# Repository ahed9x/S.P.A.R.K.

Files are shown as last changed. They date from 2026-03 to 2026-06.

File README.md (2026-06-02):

---
title: "S.P.A.R.K."
author: "ahed9x"
description: "ping pong no camera refree"
created_at: "2026-01-07"
---

# ⚡ S.P.A.R.K.

> an acoustic ping pong referee. 15 sensors, 3 esp32s, zero cameras.

## why i built this
last summer i wasted weeks trying to train a computer vision model to track a ping pong ball. the frame rates were terrible, the processing lagged, and it basically sucked. then one day i was sitting by the table waiting for my turn, closed my eyes, and realized i could track the score and whose turn it was just by listening to the bounces. 

it clicked that acoustic time-of-flight on edge microcontrollers would be way faster for catching a 100km/h ball without needing a crazy gpu. so i scrapped the camera and built this instead.

## what it actually is
SPARK is a fully automated table-tennis referee. it uses 4 i2s microphones on the corners of the table to listen for the ball, and calculates the exact x/y coordinate of the hit using time-difference-of-arrival (TDOA) math. i also glued 10 lm393 piezo sensors under the table and net to catch instant physical vibrations. 

everything gets processed by a master esp32 that runs the game logic, drives a 5m led scoreboard, and yells the score out through a speaker.



## the architecture (why 3 chips?)
at first i tried to run this on one or two chips, but the interrupts kept crashing. ping pong is way too fast. if the esp is busy updating the led strip, it misses the sound of the bounce. 

the biggest hurdle was clock sync. all 4 microphones MUST share the exact same internal hardware clock. if i split them across different chips, the microsecond time-of-flight math drifts and the coordinates get completely ruined. 

so i split the load:
* **s3 alpha (left side):** handles all 4 mics (to keep the clock perfectly synced) + the left side piezos.
* **s3 beta (right side):** handles the right side piezos + the net piezos.
* **master wroom:** runs the actual game logic, the bme680, audio amp, and led scoreboard.

alpha and beta just act as raw sensor nodes and fire data back to the master over hardwired UART.

## the math & physics
**speed of sound drift:** the speed of sound literally changes depending on how hot the room is. if i don't account for this, the math drifts. i threw a bme680 sensor on the master board to constantly read the room temp in celsius and update the velocity variable in real time.

**tdoa (time difference of arrival):** 4 mics give us 3 independent arrival time differences. instead of running crazy non-linear solvers that would lag the esp, the system linearizes the equations into a 3x3 matrix and solves it instantly using cramer's rule. 

**analog vs digital piezos:** initially i tried reading the piezos via analog pins. terrible idea. the esp wasted too many cycles polling the voltage. i switched to lm393 modules so the hardware handles the threshold tuning. when a ball hits, it fires a digital HIGH, triggering a zero-latency hardware interrupt.

## the wiring nightmare
no custom pcb yet, it's all point-to-point. 

running raw uart and i2s data wires across a 2.7 meter table turns them into giant antennas that pick up massive emi static from the 15A power supply. it was a devastating process figuring out why the signals were garbage. i ended up using cat5e ethernet cables for the long data runs—twisting the rx/tx lines with ground wires inside the cat5e physically shields the signals.

Schematic_New-Projecterewrewrwer_2026-03-12 (1)
[Schematic_New-Projecterewrewrwer_2026-03-12 (1).pdf](https://github.com/user-attachments/files/28225490/Schematic_New-Projecterewrewrwer_2026-03-12.1.pdf)

## 3d printed parts & acoustic shadows
i couldn't drill holes in the table (obviously), so everything mounts with vhb tape. 

i also originally wanted to mount the mics deep underneath the table to protect them, but realized the thick wooden edge creates an "acoustic shadow" that bends and delays the sound wave. that delay completely destroys the millimeter accuracy. i had to design custom fusion 360 brackets that extend out and keep the mic entry hole perfectly flush with the table surface.

full assembly
ESP Case
Mic Holder

## the build / bom
the whole thing costs around 6492 EGP (like 125 USD). 




* 2x ESP32-S3-N16R8
* 1x ESP32 WROOM
* 4x INMP441 MEMS Mics
* 10x LM393 Piezo Modules
* 1x BME680 Sensor
* 1x MAX98357A I2S Amp + 3W Speaker
* 5m WS2812B LEDs + 15A PSU
* lots of CAT5E cable

all cad files are in the `/cad` folder on this repo. 

image (1)
image (2)

## quick start
1. flash all 3 esps using platformio.
2. grab the mac addresses of the alpha and beta chips and drop them into `shared/spark_protocol.h` on the master.
3. put your game audio `.wav` files (16-bit pcm, mono) onto a fat32 micro sd card and pop it into the master module.
4. connect to the `SPARK_Table` wifi network, hit `192.168.4.1`, and hit new game.

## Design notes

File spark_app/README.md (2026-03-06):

# spark_app

A new Flutter project.

## Getting Started

This project is a starting point for a Flutter application.

A few resources to get you started if this is your first Flutter project:

- [Lab: Write your first Flutter app](https://docs.flutter.dev/get-started/codelab)
- [Cookbook: Useful Flutter samples](https://docs.flutter.dev/cookbook)

For help getting started with Flutter development, view the
[online documentation](https://docs.flutter.dev/), which offers tutorials,
samples, guidance on mobile development, and a full API reference.

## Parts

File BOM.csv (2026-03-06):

Category | Qty | Item Name | Purpose / Notes | Estimated Price (EGP) | link
MCU & Logic | 2 | ESP32-S3-1N16R8 WiFi + Bluetooth | S3 Alpha & Beta (Audio Buffering & Interrupts) | 900 | https://store.fut-electronics.com/collections/all/products/esp32-s3-devkitc-1-copy?variant=43309674496109
MCU & Logic | 1 | ESP32-S3 (DevKitC-1) | Master WROOM (Game Engine & API Server) | 380 | https://store.fut-electronics.com/collections/all/products/esp32-s3-devkitc-1?variant=42265460179053
MCU & Logic | 1 | 4 Channels I2C Logic Level Converter | 3.3V to 5V shifter for the LED strip data line | 45 | https://store.fut-electronics.com/collections/all/products/logic-level-converter-1?variant=40470370025581
MCU & Logic | 1 | Micro SD Card Module (5V Compatible) | Reads audio files and local player JSON data | 60 | https://www.ram-e-shop.com/ar/shop/kit-sd-card-module-micro-sd-card-module-for-arduino-or-mcu-7056
MCU & Logic | 1 | Micro SD Card 32 GB HC10 | High-speed storage for web assets and audio | 375 | https://www.ram-e-shop.com/ar/shop/micro-sd-32gb-micro-sd-card-32gb-hc10-krt-dhkr-mymwry-micro-sd-s-32-jyjbyt-6298
Sensors & Audio | 4 | INMP441 MEMS Microphone - I2S | Corner acoustic ToF mapping | 1120 | https://store.fut-electronics.com/collections/all/products/inmp441-mems-microphone-i2s?variant=43298631417965
Sensors & Audio | 10 | Piezo Sensor Element 35mm | Vibration sensing and acoustic ping emission | 350 | https://store.fut-electronics.com/collections/all/products/piezo-sensor-element-35mm?variant=40109101547629
Sensors & Audio | 10 | Vibration Switch Module SW1801P | Using the LM393 chips for digital hardware interrupts | 250 | https://makerselectronics.com/product/vibration-switch-module-sw1801p/
Sensors & Audio | 1 | BME680 Environmental Sensor | Speed of Sound calculation & enclosure thermal monitoring | 490 | https://store.fut-electronics.com/collections/all/products/bme680-environmental-sensor-pressure-temperature-humidity-voc-gas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
Sensors & Audio | 1 | MAX98357A I2S Amplifier (or PAM8403) | Required to drive the 3W speaker safely from the ESP32 | 120 | https://makerselectronics.com/product/max98357a-i2s-amplifier-module/
Sensors & Audio | 1 | YD66-2 Speaker 8 Ohm 3W | Game announcer and UI sound effects | 24 | https://makerselectronics.com/product/yd66-2-speaker-8%cf%89-3w-66mmx21mm/
Power & Wiring | 1 | Power Supply 5V 15A | Main heavy-duty power for LEDs and system | 325 | https://makerselectronics.com/product/power-supply-5v-15a/
Power & Wiring | 1 | AC-04 AC Power Socket 3 Pin Male | Professional mains connection for the Control Box | 9 | https://makerselectronics.com/product/socket-3-pin-male-connector-10a-250v/
Power & Wiring | 1 | Ac Power Cord Cable 1.75m | Plugs the Control Box into the wall | 45 | https://www.ram-e-shop.com/ar/shop/power-cable-comp-ac-power-cord-cable-1-75m-kbl-bwr-kbl-kmbywtr-twl-1-75-mtr-5621
Power & Wiring | 1 | WS2812 RGB LED Strip 60LED/m (5m) | Visual scoreboard and game state feedback | 750 | https://makerselectronics.com/product/ws2812-addressable-rgb-waterproof-le/
Power & Wiring | 20 | UTP CAT5E Ethernet Cable (Meters) | Twisted pairs for hardwired UART & sensor data | 100 | https://makerselectronics.com/product/utp-cat5e-tia-eia-ethernet-cable/
Power & Wiring | 5 | Stranded Wire 1.5mm Red (Meters) | 15A Main Positive power rail under the table | 75 | https://makerselectronics.com/product/stranded-wire-1-5mm%c2%b2-1meter/?attribute_color=Red
Power & Wiring | 5 | Stranded Wire 1.5mm Black (Meters) | 15A Main Ground power rail under the table | 75 | https://makerselectronics.com/product/stranded-wire-1-5mm%c2%b2-1meter/?attribute_color=Black
Power & Wiring | 5 | Audio Speaker Cable 2x2mm (Meters) | Power injection lines to prevent LED voltage drop | 65 | https://makerselectronics.com/product/audio-speaker-cable-2x2mm/
Cooling & Safety | 8 | Aluminum Heatsink HS.1 (9x9x12mm) | Thermal dissipation for the S3 chips | 200 | https://www.ram-e-shop.com/ar/shop/hs1-aluminum-heatsink-hs-1-size-9x9x12-mm-mbrd-hrry-hyt-synk-lwmnywm-5979
Cooling & Safety | 1 | MX-6 ARCTIC Thermal Paste 2g | High-performance heat transfer (center of chip) | 225 | https://makerselectronics.com/product/mx-6-arctic-grey-high-copy-thermal-paste-2g/
Cooling & Safety | 1 | Super Glue 3.2g | Permanent heatsink anchoring (corners of chip) | 26 | https://www.ram-e-shop.com/ar/shop/glue-3gm-super-glue-3-2g-lsq-swbr-jlw-lsrwkh-3-2-jm-6930
Cooling & Safety | 3 | 5v dc 3010 30x30x10 fan | Active emergency airflow for the Control Box | 300 | Active emergency airflow for the Control Box
Cooling & Safety | 3 | IRF520 MOSFET or TIP120 Transistor | Allows ESP32 to PWM control the 5V fan silently | 60 | https://makerselectronics.com/product/irf520-n-channel-power-mosfet-to-220/
Components | 10 | Carbon Resistor 1M Ohm 0.25W | Bleed resistors for the 35mm piezos | 10 | https://makerselectronics.com/product/carbon-resistor-1m%cf%89-0-25w-through-hol/
Components | 10 | Zener Diode 5.1V 0.5W | Overvoltage spike protection for ESP32 inputs | 23 | https://makerselectronics.com/product/zener-diode-5-1v-0-5w/

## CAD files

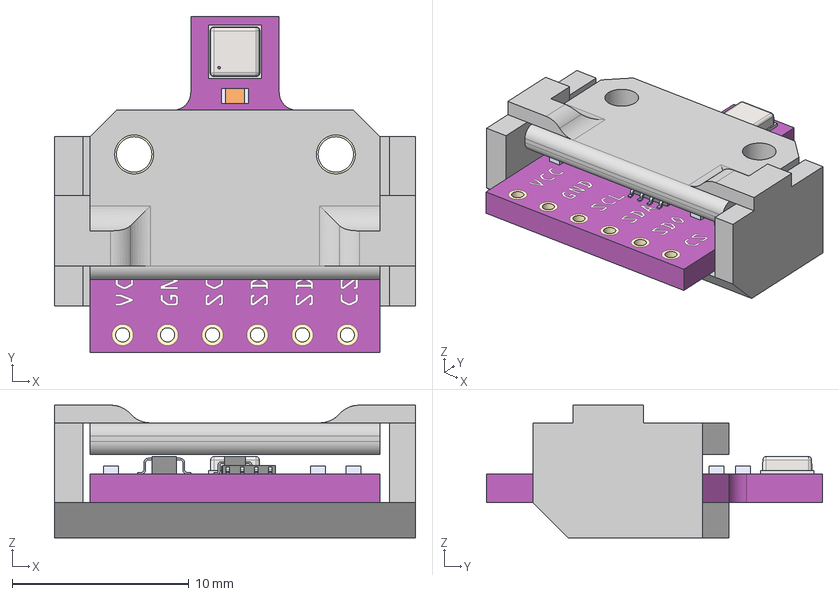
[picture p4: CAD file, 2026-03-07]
cad/sensor holder.step
20.4 x 19.0 x 7.50 mm

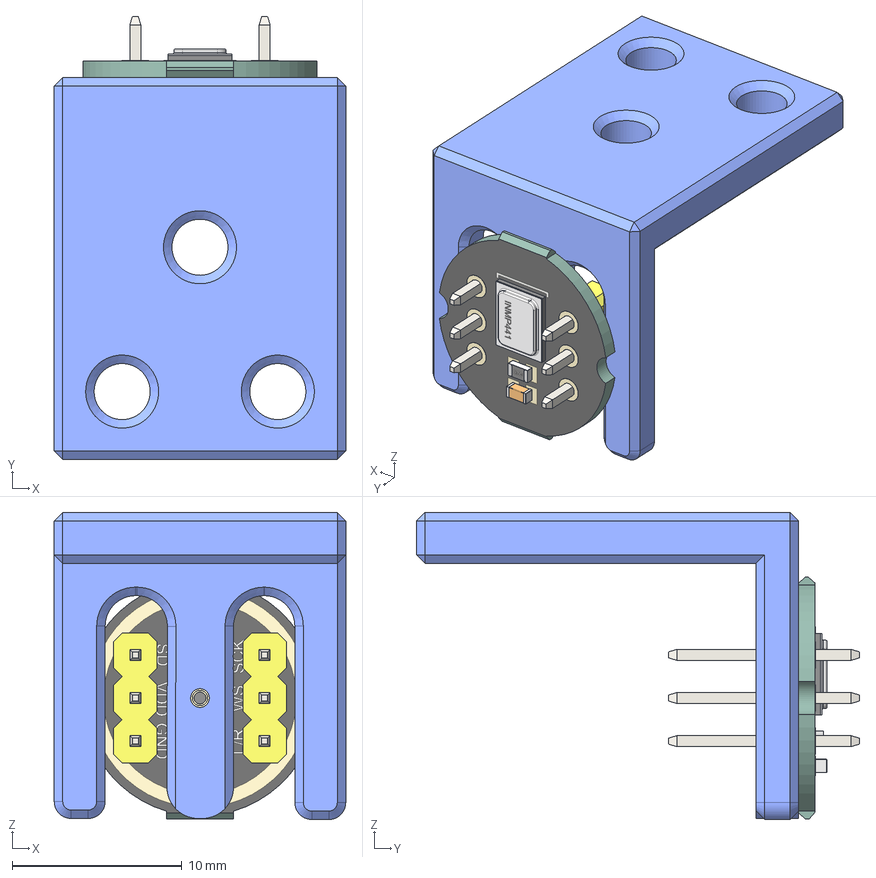
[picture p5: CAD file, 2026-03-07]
cad/mic holder.step
17.2 x 26.1 x 18.1 mm

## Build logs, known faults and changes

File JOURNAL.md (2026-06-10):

---
title: "S.P.A.R.K."
author: "ahed9x"
description: "ping pong no camera refree"
created_at: "2026-01-07"
---
# Collected the BOM

i collected everything i will need for this one and understood all the concepts for it to work, it is medium in difficulty but highly rewarding and better than using a camera because cameras have frame rate limits and computer vision adds way too much processing lag. acoustic time of flight on edge microcontrollers is way faster for catching a 100km/h ball without needing a crazy gpu.

1x WS2812 Addressable RGB LED Strip (5m) — 750.00 EGP
1x Power Supply 12V 30A — 625.00 EGP
1x Power Supply 5V 20A — 395.00 EGP
2x Power Cable 6-16A (1.5m) — 50.00 EGP
2x AC Power Plug 250V Male — 34.00 EGP
1x Speaker 4 Ohm 3W (55mm) — 20.00 EGP
1x MAX98357A I2S Amplifier Module — 120.00 EGP
15x UTP CAT6 Ethernet Cable (Meters) — 120.00 EGP
2x Red & Black Audio Cable (Meters) — 12.00 EGP
2x Blue & Transparent Audio Cable (Meters) — 26.00 EGP
5x LED Strips Connecting Cable (Meters) — 67.50 EGP
1x ESP32-S3-N16R8 Development Board — 550.00 EGP
10x Piezo Buzzer Element (35mm) — 350.00 EGP
2x INMP441 MEMS Microphone — 560.00 EGP (Assuming 280 EGP each)
1x Neon Flexible LED Strip Roll 50M (Yellow) — 1,600.00 EGP
SHIPPING: 135egp
Total: 5,414.50 EGP









**Total time spent: 2.5 hours**

# Creating the sketch

SCHNew-Project2026-01-07

SchematicNew-Project2026-01-07
i created everything i am nearly ready to start building in real life after i finish the basic code. realized using analog pins for the piezos would take too many milliseconds for the esp to poll the voltage, so using lm393 modules instead to get instant digital hardware interrupts so the esp doesn't waste processing cycles.

[Schematic_New-Project_2026-01-07.pdf](https://github.com/user-attachments/files/28225953/Schematic_New-Project_2026-01-07.pdf)



[Schematic_New-Project_2026-01-07](/user-attachments/blobs/proxy/eyJfcmFpbHMiOnsiZGF0YSI6NzYxNTcsInB1ciI6ImJsb2JfaWQifX0=--2059aeb7d20e58d1e6439206101da1397c563e8a/Schematic_New-Project_2026-01-07.pdf)

**Total time spent: 3.5 hours**

# Firmware

using GitHub Copilot and gemini i created the first script that is ready for deployment along with the flutter app in seconds and these will maybe see some modifications when creating. i mainly used the ai to scaffold the basic flutter ui boilerplate, but the actual i2s dma buffers and microsecond hardware interrupts had to be manually hand-coded because the ai doesn't understand the strict physics timing needed for the sound waves. also I removed 1 esp and 2 mics from the project because they are unnecessary.



**Total time spent: 0.2 hours**

# Rethinking the design

I heavily researched and will shift to a completely new plan:
first we will use 3 esps 1 for 4 mics and 4 piezos, and another for 6 piezos with a master one for the game logic, sd, speaker, and lights. Further, we added an SD card and a temperature, humidity, and pressure sensor all in one (since the speed of sound changes based on temperature, the math needs dynamic adjusting).
also i figuered out 50m of LEDs is an overkill, and I shall not ask for that here.

why?
by using 3 esps we ensure the detection is completely separate from anything else. Ping-pong is a very fast game the ball can reach up to 100+km/h, which needs insanely fast detection, so using only 2 ESPs will lead to sometimes the LED control or sound control interfering with gameplay detection, possibly missing hits. Second, could you explain why one ESP uses two mics and five piezos while the other uses the same? the answer is fairly simple the mic system is seperate from the piezo system and shall be monitored alone so dividing both on both esps will force us to create a insanely complex highway connection between both esps and we must ensure clock sync then; instead if we make 1 esp calculate all mic input and the right side of the table piezo grid and one control the elft side along with net we remmove all the hurdle of syncing because all 4 mics will now share the exact same internal hardware master clock, which is literally the only way the time-of-flight math works without drifting.







**Total time spent: 7.0 hours**

# Designing ESP Case

In Fusion 360, I designed a case with a mini fan for the ESP. For the lowest noise, the fans will work only if heat is detected not to disturb players and because any extra fan motor vibrations vibrating through the table could accidentally trigger the piezos and mess up the hardware interrupts; however, the design might still need more tweaking.






**Total time spent: 2.0 hours**

# Finished the new code

i created the initial code but it still also needs high refinement when all components arrive to make it perfect through tuning because filtering out false bounces via software introduces too much latency, so I am going to rely mostly on tuning the physical potentiometers on the LM393 boards.




...

**Total time spent: 1.0 hour**

# Creating the GitHub repo

I uploaded everything to GitHub, and the repo is fully ready. I even created the BOM CSV with links and prices, and used highly detailed information, making the project nearly complete




**Total time spent: 1.0 hour**

# Wiring and final details



The new total project cost is 8720egp or 175 USD, including shipping

Master Brain (ESP32 WROOM 32)
BME680: SDA -> 21 | SCL -> 22
SD Card: MOSI -> 23 | MISO -> 19 | SCK -> 18 | CS -> 5
MAX98357A (Amp): BCLK -> 26 | LRC -> 25 | DIN -> 27
UART 1 (From Alpha): RX -> 32 | TX -> 33
UART 2 (From Beta): RX -> 16 | TX -> 17
LED Data: 13 (Goes to Level Shifter LV1)
Fan PWM: 14 (Goes to MOSFET Gate)
S3 Alpha (ESP32-S3-1N16R8)
Front Mics (1 & 2): SCK -> 4 | WS -> 5 | SD -> 6
Back Mics (3 & 4): SCK -> 7 | WS -> 8 | SD -> 9
Side A Piezos (LM393 D0): 10, 11, 12, 13
Calibration Buzzer Bypass: 14 (Direct to Piezo 1 positive)
UART (To Master): TX -> 17 | RX -> 18
S3 Beta (ESP32-S3-1N16R8)
Side B Piezos (LM393 D0): 4, 5, 6, 7
Net Piezos (LM393 D0): 8, 9
UART (To Master): TX -> 17 | RX -> 18
Logic Level Shifter (For WS2812B LEDs)
LV -> ESP32 3.3V
LV1 -> Master Pin 13
LV GND -> ESP32 GND
HV -> 15A PSU 5V
HV1 -> LED Strip Data IN
HV GND -> 15A PSU GND
MOSFET (For 5V 60mm Fan)
Gate (SIG) -> Master Pin 14
Drain -> Fan Black Wire (-)
Source -> 15A PSU GND & ESP32 GND
Fan Red Wire (+) -> 15A PSU 5V
Power & CAT5E Rules
ALL components (ESP32s, modules, shifter, MOSFET, LED strip) MUST share the 15A PSU Ground (-).
CAT5E UART pairs: Orange = TX + GND. Green = RX + GND. had to do this because running raw data wires across a 2.7m table turns them into giant antennas that pick up massive emi static from the 15A psu, so twisting them with ground inside the ethernet cable physically shields the signals.

**Total time spent: 1.0 hour**

# Designing all Cad Parts Needed

I designed almost all cad parts needed to hold the electronics. Other electronics will be directly screwed or taped to the table and all CAD models will be on GitHub soon:
!!UPDATE: I uploaded them on GitHub [https://github.com/ahed9x/S.P.A.R.K./tree/main/cad](https://github.com/ahed9x/S.P.A.R.K./tree/main/cad). realized i couldn't just mount the mics deep under the table either because the thick wooden edge creates an acoustic shadow that delays the sound wave from reaching it, so the custom fusion 360 brackets extend to keep the mic entry hole perfectly flush with the surface.

image (5)
image (6)
image (7)


**Total time spent: 2.0 hours**

# Explaining SPARK

So briefly, in this project, I aim to make use of the time of arrival of the sound emitted by the ping pong ball to calculate where it hit on the table/ paddle in the air, thus creating an auto ping pong referee, gamifying the process through LEDs, speakers, and the app.
core features:
1- on table ball hit mapping (x,y coordinates where the ball hits table)
2- in air paddle hit ball mapping (x,y,z coordinates where player hit ball)
3- ball net hit detection (detects when the ball hits the net)
4- interactive live addressable RGB LED strip (everything changes according to ball hits and points)
5- Gamified process through app and sound controls
6- Auto full refree combining all data to be the refree calculating points, penalties, and serves



**Total time spent: 1.0 hour**

# Creating new wiring schematic

I finally created the wiring schematic for the whole project. It was a pretty devastating process!

SchematicNew-Projecterewrewrwer2026-03-12 (1)
SchematicNew-Projecterewrewrwer2026-03-12 (1)
SCHNew-Projecterewrewrwer2026-03-12 (1)

Schematic_New-Projecterewrewrwer_2026-03-12 (1)
[Schematic_New-Projecterewrewrwer_2026-03-12 (1).pdf](https://github.com/user-attachments/files/28225490/Schematic_New-Projecterewrewrwer_2026-03-12.1.pdf)

Schematic_New-Projecterewrewrwer_2026-03-12 (1)

**Total time spent: 3.0 hours**

# Finished the full CAD assembly

I finished the final full CAD assembly and noted that we can't poke holes and screws through the ping pong table, so everything will be glued/taped, or the table will be ruined.

image (1)
image (2)
image (4)
image (3)

**Total time spent: 1.0 hour**

# Github

I uploaded everything on github:
Code: [https://github.com/ahed9x/S.P.A.R.K](https://github.com/ahed9x/S.P.A.R.K).
BOM: [https://github.com/ahed9x/S.P.A.R.K./blob/main/BOM.csv](https://github.com/ahed9x/S.P.A.R.K./blob/main/BOM.csv)
the 3d design files: [https://github.com/ahed9x/S.P.A.R.K./tree/main/cad](https://github.com/ahed9x/S.P.A.R.K./tree/main/cad)
amp holder- [https://github.com/ahed9x/S.P.A.R.K./blob/main/cad/amp%20holder.step](https://github.com/ahed9x/S.P.A.R.K./blob/main/cad/amp%20holder.step)
mic holder- [https://github.com/ahed9x/S.P.A.R.K./blob/main/cad/mic%20holder.step]()
esp holder- [http://github.com/ahed9x/S.P.A.R.K./blob/main/cad/esp%2032%20s3%20case.step]()
sensor holder- [https://github.com/ahed9x/S.P.A.R.K./blob/main/cad/sensor%20holder.step]()
ASSEMBLY - [https://github.com/ahed9x/S.P.A.R.K./blob/main/cad/Full%20Assembly.zip]() [https://github.com/ahed9x/S.P.A.R.K./blob/main/cad/Full%20Assembly.f3z]()



**Total time spent: 0.1 hours**

# Summary

- I won't buy the acoustic because it feels very irrelevant, and just to make it clear, even though the problem can be solved via code, it will add latency, which can differ in a sport like ping pong. 
- Second, the latest uploaded architecture with 3 esps will be used to ensure accuracy and speed.
- The total final cost will be around 6492 egp or 125 USD at this time, May 25, 2026, which may fluctuate +-20usd


**Total time spent: 0.1 hours**

# Edits

As github shows, i started this project a couple of months ago and in egypt stocks are very fluctuating, for example, the esp s3 is no more in stock and isnt in any electronics store here except a similar version that has the same capabilities but is in the Arduino Uno R3 PCB design so I updated the cart to the latest in-stock stuff and switched some things to accommodate for no longer avaliable stuff.









the new total is 6688.5 egp or around 129 usd



**Total time spent: 3.5 hours**

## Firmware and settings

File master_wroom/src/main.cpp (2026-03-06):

/*******************************************************************************
 * SPARK — Master WROOM  v3.0  (Hardwired UART + WebSocket API)
 *
 * Hardware
 *   • ESP32-WROOM-32  (4 MB Flash)
 *   • BME680           (I2C  SDA 21 / SCL 22)
 *   • 5 V PWM Fan      (GPIO 4 via N-MOSFET)
 *   • MAX98357A I2S Amp (BCLK 27 / LRCLK 12 / DIN 14)  +  3 W Speaker
 *   • MicroSD Card      (SPI  MOSI 23 / MISO 19 / SCK 18 / CS 5)
 *   • WS2812B strip     (300 LEDs, GPIO 13, 3.3→5 V level-shifted)
 *
 * v3.0 Changes  (from v2.0)
 *   • Removed ESP-NOW entirely.  Inter-node comms now use hardwired UART
 *     over CAT5E Ethernet cable for commercial-grade reliability.
 *   • Serial1 (RX 16 / TX 17)  ↔  S3 Alpha
 *   • Serial2 (RX 25 / TX 26)  ↔  S3 Beta
 *   • Fan PWM moved from GPIO 25 → GPIO 4  (25 is now UART2 RX)
 *   • I2S BCLK moved from GPIO 26 → GPIO 27, LRCLK from 27 → 12
 *     (26 is now UART2 TX)
 *   • WiFi runs as pure STA for LAN access (no AP needed for ESP-NOW).
 *
 * Wiring  (CAT5E, ≤ 3 m, alongside 15 A LED power rail)
 *   ─────────────────────────────────────────────────────────
 *   Cable A  (Master ↔ S3 Alpha):
 *     Orange pair:  Solid = Master TX (17) → Alpha RX (18),  Striped = GND
 *     Green  pair:  Solid = Alpha  TX (17) → Master RX (16), Striped = GND
 *
 *   Cable B  (Master ↔ S3 Beta):
 *     Orange pair:  Solid = Master TX (26) → Beta RX (18),   Striped = GND
 *     Green  pair:  Solid = Beta   TX (17) → Master RX (25), Striped = GND
 *
 *   CRITICAL: pair each data line with GND on the striped wire.
 *   ─────────────────────────────────────────────────────────
 ******************************************************************************/

#include <Arduino.h>
#include <WiFi.h>
#include <driver/i2s.h>
#include <SPI.h>
#include <SD.h>
#include <Wire.h>
#include <Adafruit_BME680.h>
#include <FastLED.h>
#include <WebSocketsServer.h>
#include <ArduinoJson.h>
#include <freertos/FreeRTOS.h>
#include <freertos/task.h>
#include <freertos/queue.h>
#include "spark_protocol.h"

/* ===========================================================================
 *                       NETWORK CONFIGURATION
 * =========================================================================*/

// Local WiFi router credentials — change to match your network
#define WIFI_SSID     "YOUR_WIFI_SSID"
#define WIFI_PASS     "YOUR_WIFI_PASSWORD"
#define WS_PORT       81

/* ===========================================================================
 *                          PIN DEFINITIONS
 *
 *  GPIO 16 = UART1 RX (Alpha)    GPIO 17 = UART1 TX (Alpha)
 *  GPIO 25 = UART2 RX (Beta)     GPIO 26 = UART2 TX (Beta)
 *  ↑ These 4 pins are now reserved for inter-node UART.
 * =========================================================================*/

#define BME_SDA     21
#define BME_SCL     22

#define FAN_PIN     4           // moved from 25 (now UART2 RX)
#define FAN_CH      0
#define FAN_FREQ    25000
#define FAN_RES     8

#define I2S_BCLK    27          // moved from 26 (now UART2 TX)
#define I2S_LRCLK   12          // moved from 27 (taken by BCLK)
#define I2S_DIN     14

#define SD_MOSI     23
#define SD_MISO     19
#define SD_SCK      18
#define SD_CS       5

#define LED_PIN     13
#define NUM_LEDS    300
#define LED_BRIGHT  178

#define LED_A_START   0
#define LED_A_END   124
#define LED_NET_START 125
#define LED_NET_END   174
#define LED_B_START   175
#define LED_B_END     299

/* ===========================================================================
 *                          GLOBALS
 * =========================================================================*/

static Adafruit_BME680    bme;
static CRGB               leds[NUM_LEDS];
static WebSocketsServer   wsServer(WS_PORT);

// ---- UART receive state machines ----
static UartRxState        gRxAlpha;       // Serial1 — S3 Alpha
static UartRxState        gRxBeta;        // Serial2 — S3 Beta

// ---- Environment ----
static float    gTemp           = 25.0f;
static float    gHumidity       = 50.0f;
static float    gPressure       = 1013.25f;
static float    gSpeedOfSound   = 343.0f;
static uint8_t  gFanPWM         = 0;

// ---- Game state ----
static uint8_t   gScoreA        = 0;
static uint8_t   gScoreB        = 0;
static uint8_t   gServer        = 0;
static uint8_t   gFirstServer   = 0;
static GameState gState         = GS_IDLE;
static int64_t   gStateTime     = 0;
static bool      gNetTouched    = false;
static uint8_t   gExpectedBounce = 0;
static uint16_t  gRallyCount    = 0;

// ---- LED animation ----
static LEDMode   gLedMode       = LED_IDLE;
static uint32_t  gLedStart      = 0;

// ---- Audio queue ----
static QueueHandle_t qAudio     = nullptr;

// ---- Hit ring buffer ----
#define MAX_HITS 200
struct HitRecord { float x; float y; float velocity; uint8_t zone; };
static HitRecord gHits[MAX_HITS];
static int       gHitCount = 0;
static int       gHitIdx   = 0;

// ---- Calibration state ----
static bool    gCalibrationMode = false;
static uint8_t gCalibStep       = 0;

/* ===========================================================================
 *                  FORWARD DECLARATIONS
 * =========================================================================*/
static void processEvent(const uint8_t* data, int len);
static void awardPoint(uint8_t toSide);
static void updateServerRotation();
static void enterState(GameState ns);
static void updateLEDs();
static void wsBroadcast(const char* json);
static void wsPushState();
static void wsPushHit(float x, float y, float velocity, const char* evt);
static void wsPushPiezo(uint8_t nodeId, uint8_t sensorId, SensorZone zone);
static void wsPushCalibration();
static void wsPushEvent(const char* event, const char* detail);
static void playSound(const char* path);

/* ===========================================================================
 *                  BME680  +  SPEED OF SOUND  +  FAN PWM
 * =========================================================================*/

static void updateEnvironment() {
    if (!bme.performReading()) return;
    gTemp         = bme.temperature;
    gHumidity     = bme.humidity;
    gPressure     = bme.pressure / 100.0f;
    gSpeedOfSound = calcSpeedOfSound(gTemp, gHumidity);

    if      (gTemp < 35.0f)  gFanPWM = 0;
    else if (gTemp < 38.0f)  gFanPWM = 0;
    else if (gTemp < 45.0f)  gFanPWM = 77;      // 30 %
    else                     gFanPWM = 255;      // 100 %
    ledcWrite(FAN_CH, gFanPWM);
}

/// Send calibration packet to S3 Alpha so it updates its speed-of-sound.
static void broadcastCalibration() {
    CalibrationPacket cal = {};
    cal.type         = PKT_CALIBRATION;
    cal.speedOfSound = gSpeedOfSound;
    cal.temperature  = gTemp;
    cal.humidity     = gHumidity;
    cal.pressure     = gPressure;
    // Send over UART to Alpha
    uartSendPacket(Serial1, &cal, sizeof(cal));
    Serial.printf("[CAL] v=%.2f  T=%.1f  H=%.1f  P=%.1f\n",
                  gSpeedOfSound, gTemp, gHumidity, gPressure);
}

/* ===========================================================================
 *                   GAME  STATE  MACHINE
 * =========================================================================*/

static void enterState(GameState ns) {
    gState     = ns;
    gStateTime = esp_timer_get_time();
    if (ns == GS_RALLY) gRallyCount = 0;
    wsPushState();
}

static void processEvent(const uint8_t* data, int len) {
    PacketType t = (PacketType)data[0];

    /* ---- TDOA result (paddle hit) ---- */
    if (t == PKT_TDOA_RESULT && len >= (int)sizeof(TDOAResultPacket)) {
        const TDOAResultPacket* p = (const TDOAResultPacket*)data;

        static int64_t lastHitTime = 0;
        float velocity = 0;
        if (lastHitTime > 0) {
            float dt = (float)(p->timestamp_us - lastHitTime) / 1e6f;
            if (dt > 0.01f && dt < 2.0f)
                velocity = TABLE_LENGTH_MM / 1000.0f / dt;
        }
        lastHitTime = p->timestamp_us;

        gHits[gHitIdx] = {p->x, p->y, velocity, ZONE_PADDLE};
        gHitIdx = (gHitIdx + 1) % MAX_HITS;
        if (gHitCount < MAX_HITS) gHitCount++;

        wsPushHit(p->x, p->y, velocity, "paddle");

        if (gCalibrationMode) {
            char buf[128];
            snprintf(buf, sizeof(buf),
                "{\"type\":\"calibTap\",\"step\":%u,\"x\":%.1f,\"y\":%.1f}",
                gCalibStep, p->x, p->y);
            wsBroadcast(buf);
            return;
        }

        if (gState == GS_WAIT_SERVE) enterState(GS_SERVE_HIT);
        return;
    }

    /* ---- Net event ---- */
    if (t == PKT_NET_EVENT && len >= (int)sizeof(NetEventPacket)) {
        if (gState == GS_SERVE_BOUNCED || gState == GS_SERVE_HIT)
            gNetTouched = true;
        wsPushHit(TABLE_HALF_MM, TABLE_WIDTH_MM / 2.0f, 0, "net");
        wsPushEvent("net", "Net touched");
        return;
    }

    /* ---- Piezo event (table bounce) ---- */
    if (t == PKT_PIEZO_EVENT && len >= (int)sizeof(PiezoEventPacket)) {
        const PiezoEventPacket* p = (const PiezoEventPacket*)data;
        SensorZone zone = p->zone;

        wsPushPiezo(p->nodeId, p->sensorId, zone);

        switch (gState) {
        case GS_SERVE_HIT: {
            uint8_t serverSide = (gServer == 0) ? ZONE_SIDE_A : ZONE_SIDE_B;
            if (zone == serverSide) {
                enterState(GS_SERVE_BOUNCED);
                wsPushEvent("serve_bounce", "Serve bounced on server side");
            }
            break;
        }
        case GS_SERVE_BOUNCED: {
            uint8_t recvSide = (gServer == 0) ? ZONE_SIDE_B : ZONE_SIDE_A;
            if (zone == recvSide) {
                if (gNetTouched) {
                    enterState(GS_LET);
                    gLedMode = LED_LET_YELLOW; gLedStart = millis();
                    playSound(WAV_LET);
                    wsPushEvent("let", "LET — replay serve");
                } else {
                    gExpectedBounce = (gServer == 0) ? ZONE_SIDE_A : ZONE_SIDE_B;
                    enterState(GS_RALLY);
                    gLedMode = LED_SERVE_PULSE; gLedStart = millis();
                    wsPushEvent("rally", "Rally begins");
                }
                gNetTouched = false;
            }
            break;
        }
        case GS_RALLY: {
            gRallyCount++;
            if (zone == gExpectedBounce) {
                gExpectedBounce = (gExpectedBounce == ZONE_SIDE_A)
                                  ? ZONE_SIDE_B : ZONE_SIDE_A;
                gStateTime = esp_timer_get_time();
            } else {
                uint8_t winner = (zone == ZONE_SIDE_A) ? 1 : 0;
                awardPoint(winner);
            }
            break;
        }
        default: break;
        }
        return;
    }

    /* ---- Heartbeat ---- */
    if (t == PKT_HEARTBEAT) {
        const HeartbeatPacket* hb = (const HeartbeatPacket*)data;
        char buf[96];
        snprintf(buf, sizeof(buf),
            "{\"type\":\"heartbeat\",\"node\":%u,\"uptime\":%u,\"status\":%u}",
            hb->nodeId, hb->uptimeMs, hb->status);
        wsBroadcast(buf);
    }
}

static void checkTimeouts() {
    int64_t now   = esp_timer_get_time();
    int64_t delta = now - gStateTime;

    switch (gState) {
    case GS_SERVE_HIT:
        if (delta > SERVE_TIMEOUT_US) {
            awardPoint(1 - gServer);
            wsPushEvent("fault", "Serve timeout — fault");
        }
        break;
    case GS_SERVE_BOUNCED:
        if (delta > SERVE_TIMEOUT_US) {
            awardPoint(1 - gServer);
            wsPushEvent("fault", "Serve not returned");
        }
        break;
    case GS_RALLY:
        if (delta > RALLY_BOUNCE_TIMEOUT_US) {
            uint8_t winner = (gExpectedBounce == ZONE_SIDE_A) ? 0 : 1;
            awardPoint(winner);
            wsPushEvent("out", "Ball out — rally timeout");
        }
        break;
    case GS_LET:
        if (delta > 2000000) {
            enterState(GS_WAIT_SERVE);
            gLedMode = LED_SCORE; gLedStart = millis();
        }
        break;
    case GS_POINT:
        if (delta > 2000000) {
            enterState(GS_WAIT_SERVE);
            gLedMode = LED_SCORE; gLedStart = millis();
        }
        break;
    default: break;
    }
}

/* ===========================================================================
 *                    SCORING  &  SERVICE  ROTATION
 * =========================================================================*/

static void awardPoint(uint8_t toSide) {
    if (toSide == 0) {
        gScoreA++;
        gLedMode = LED_POINT_GREEN; gLedStart = millis();
        playSound(WAV_POINT_A);
        wsPushEvent("point", "Point Player A");
    } else {
        gScoreB++;
        gLedMode = LED_POINT_GREEN; gLedStart = millis();
        playSound(WAV_POINT_B);
        wsPushEvent("point", "Point Player B");
    }

    uint8_t prev = gServer;
    updateServerRotation();
    if (gServer != prev) {
        playSound(WAV_CHANGE_SERVER);
        wsPushEvent("serve_change", gServer == 0 ? "Service → A" : "Service → B");
    }

    if (gScoreA >= 10 && gScoreB >= 10 && gScoreA == gScoreB)
        playSound(WAV_DEUCE);
    if ((gScoreA == 10 && gScoreB < 10) || (gScoreB == 10 && gScoreA < 10))
        playSound(WAV_MATCH_POINT);

    bool over = false;
    if (gScoreA >= 11 && gScoreA - gScoreB >= 2) over = true;
    if (gScoreB >= 11 && gScoreB - gScoreA >= 2) over = true;

    if (over) {
        enterState(GS_GAME_OVER);
        gLedMode = LED_GAME_OVER; gLedStart = millis();
        playSound(WAV_GAME_OVER);
        char buf[160];
        snprintf(buf, sizeof(buf),
            "{\"type\":\"gameOver\",\"winner\":%u,\"scoreA\":%u,\"scoreB\":%u,\"rally\":%u}",
            toSide, gScoreA, gScoreB, gRallyCount);
        wsBroadcast(buf);
    } else {
        enterState(GS_POINT);
    }
    wsPushState();
}

static void updateServerRotation() {
    int total = gScoreA + gScoreB;
    bool deuce = (gScoreA >= 10 && gScoreB >= 10);
    int turns = deuce ? (10 + total - 20) : (total / 2);
    gServer = (turns % 2 == 0) ? gFirstServer : (1 - gFirstServer);
}

/* ===========================================================================
 *                  LED  STRIP  (same animations as v1)
 * =========================================================================*/

static void showScore() {
    int ledsPerPt = 11;
    int litA = min((int)gScoreA * ledsPerPt, 125);
    for (int i = LED_A_START; i <= LED_A_END; ++i)
        leds[i] = (i < LED_A_START + litA) ? CRGB(0xFF, 0x20, 0x20) : CRGB::Black;
    int litB = min((int)gScoreB * ledsPerPt, 125);
    for (int i = LED_B_END; i >= LED_B_START; --i)
        leds[i] = ((LED_B_END - i) < litB) ? CRGB(0x20, 0x60, 0xFF) : CRGB::Black;
    for (int i = LED_NET_START; i <= LED_NET_END; ++i)
        leds[i] = CRGB(30, 30, 30);
}

static void updateLEDs() {
    uint32_t now = millis();
    uint32_t elapsed = now - gLedStart;

    switch (gLedMode) {
    case LED_OFF:
        fill_solid(leds, NUM_LEDS, CRGB::Black); break;
    case LED_IDLE: {
        uint8_t b = beatsin8(15, 20, 80);
        fill_solid(leds, NUM_LEDS, CRGB::Black);
        for (int i = LED_NET_START; i <= LED_NET_END; ++i) leds[i] = CRGB(0,0,b);
        break;
    }
    case LED_SERVE_PULSE: {
        showScore();
        uint8_t b = beatsin8(40, 60, 200);
        for (int i = LED_NET_START; i <= LED_NET_END; ++i) leds[i] = CRGB(0,0,b);
        if (elapsed > 1000) { gLedMode = LED_SCORE; gLedStart = now; }
        break;
    }
    case LED_POINT_GREEN: {
        if (elapsed < 500) {
            uint8_t g = (elapsed / 50 % 2 == 0) ? 255 : 0;
            fill_solid(leds, NUM_LEDS, CRGB(0,g,0));
        } else { showScore(); gLedMode = LED_SCORE; gLedStart = now; }
        break;
    }
    case LED_FAULT_RED: {
        if (elapsed < 600) {
            uint8_t r = (elapsed / 60 % 2 == 0) ? 255 : 0;
            fill_solid(leds, NUM_LEDS, CRGB(r,0,0));
        } else { showScore(); gLedMode = LED_SCORE; gLedStart = now; }
        break;
    }
    case LED_LET_YELLOW: {
        if (elapsed < 1500) {
            for (int i = 0; i < NUM_LEDS; ++i) {
                uint8_t wave = sin8((uint8_t)(i * 3 + elapsed / 4));
                leds[i] = CRGB(wave, wave/2, 0);
            }
        } else { showScore(); gLedMode = LED_SCORE; gLedStart = now; }
        break;
    }
    case LED_SCORE:
        showScore(); break;
    case LED_GAME_OVER: {
        for (int i = 0; i < NUM_LEDS; ++i)
            leds[i] = CHSV((uint8_t)(i*2 + elapsed/10), 255, 180);
        break;
    }
    default: break;
    }
    FastLED.show();
}

/* ===========================================================================
 *                  AUDIO  (WAV → I2S, unchanged)
 * =========================================================================*/

struct WavHeader {
    char riff[4]; uint32_t fileSize; char wave[4]; char fmt[4];
    uint32_t fmtSize; uint16_t audioFormat; uint16_t numChannels;
    uint32_t sampleRate; uint32_t byteRate; uint16_t blockAlign;
    uint16_t bitsPerSample; char data[4]; uint32_t dataSize;
};

static void audioTask(void*) {
    char path[64];
    uint8_t buf[512];
    for (;;) {
        if (xQueueReceive(qAudio, path, portMAX_DELAY) != pdTRUE) continue;
        File f = SD.open(path, FILE_READ);
        if (!f) { Serial.printf("[AUD] open FAIL %s\n", path); continue; }

        WavHeader hdr;
        if (f.read((uint8_t*)&hdr, sizeof(hdr)) != sizeof(hdr)) { f.close(); continue; }

        if (memcmp(hdr.data, "data", 4) != 0) {
            f.seek(12);
            while (f.available()) {
                char tag[4]; uint32_t sz;
                f.read((uint8_t*)tag, 4);
                f.read((uint8_t*)&sz, 4);
                if (memcmp(tag, "data", 4) == 0) { hdr.dataSize = sz; break; }
                f.seek(f.position() + sz);
            }
        }

        i2s_set_sample_rates(I2S_NUM_0, hdr.sampleRate);
        uint32_t remaining = hdr.dataSize;
        while (remaining > 0 && f.available()) {
            size_t toRead = min((size_t)remaining, sizeof(buf));
            size_t got = f.read(buf, toRead);
            if (got == 0) break;
            size_t written;
            i2s_write(I2S_NUM_0, buf, got, &written, portMAX_DELAY);
            remaining -= got;
        }
        i2s_zero_dma_buffer(I2S_NUM_0);
        f.close();
    }
}

static void playSound(const char* path) {
    xQueueSend(qAudio, path, 0);
}

/* ===========================================================================
 *          WEBSOCKET  SERVER  (port 81, with ping/pong heartbeat)
 * =========================================================================*/
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
void loop() {
    uint32_t now = millis();

    // ---- WebSocket tick ----
    wsServer.loop();

    // ---- Poll UART1 (S3 Alpha) for incoming packets ----
    {
        uint8_t  buf[256];
        uint16_t len = 0;
        while (uartPollPacket(Serial1, gRxAlpha, buf, &len))
            processEvent(buf, len);
    }

    // ---- Poll UART2 (S3 Beta) for incoming packets ----
    {
        uint8_t  buf[256];
        uint16_t len = 0;
        while (uartPollPacket(Serial2, gRxBeta, buf, &len))
            processEvent(buf, len);
    }

    // ---- Timeout checks ----
    checkTimeouts();

    // ---- Environment every 2 s ----
    if (now - lastEnv >= 2000) {
        lastEnv = now;
        updateEnvironment();
    }

    // ---- Calibration broadcast to Alpha every 60 s ----
    if (now - lastCal >= CALIBRATION_INTERVAL_MS) {
        lastCal = now;
        broadcastCalibration();
    }

    // ---- LED update every 20 ms (50 fps) ----
    if (now - lastLED >= 20) {
        lastLED = now;
        updateLEDs();
    }

    // ---- Periodic WS push every 1 s ----
    if (now - lastWSPush >= 1000) {
        lastWSPush = now;
        wsPushState();
        wsPushCalibration();
    }

    vTaskDelay(1);
}

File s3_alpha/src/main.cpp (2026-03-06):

/*******************************************************************************
 * SPARK — S3 Alpha  (Acoustic Brain + Side-A Piezos)    v2.0  UART
 *
 * Hardware
 *   • ESP32-S3  (16 MB Flash, 8 MB PSRAM)
 *   • 4× INMP441 I2S MEMS microphones  (corners of the table)
 *   • 4× 35 mm Piezos via LM393 / SW420  (Side-A corners, digital interrupt)
 *
 * Role
 *   1.  Continuously DMA-buffer stereo I2S audio from 2 buses (4 mics).
 *   2.  On a piezo interrupt OR acoustic impulse → run TDOA across 4 mic
 *       streams → multilaterate the (x, y) coordinate.
 *   3.  Forward PiezoEventPacket + TDOAResultPacket to Master via UART.
 *   4.  Accept CalibrationPacket from the Master over the same UART link.
 *
 * Wiring  (CAT5E, ≤ 3 m)
 *   ─────────────────────────────────────────────────────────
 *   This node connects to the Master WROOM via Serial1.
 *     Serial1  TX = GPIO 17   →  Master UART1 RX (GPIO 16)
 *     Serial1  RX = GPIO 18   ←  Master UART1 TX (GPIO 17)
 *
 *   CAT5E pin-out (alongside 15 A LED power rail):
 *     Orange pair:  Solid = TX,  Striped = GND
 *     Green  pair:  Solid = RX,  Striped = GND
 *   ─────────────────────────────────────────────────────────
 ******************************************************************************/

#include <Arduino.h>
#include <driver/i2s.h>
#include <freertos/FreeRTOS.h>
#include <freertos/task.h>
#include <freertos/queue.h>
#include <math.h>
#include "spark_protocol.h"

/* ===========================================================================
 *                          PIN DEFINITIONS
 * =========================================================================*/

// I2S Bus 0  — Mic 0 (L/R → GND = Left)  +  Mic 1 (L/R → VDD = Right)
#define I2S0_SCK    5
#define I2S0_WS     6
#define I2S0_SD     7

// I2S Bus 1  — Mic 2 (Left)  +  Mic 3 (Right)
#define I2S1_SCK    15
#define I2S1_WS     16
#define I2S1_SD     4       // moved from 17 (UART TX) to 4

// Side-A piezo digital inputs  (active-LOW from LM393)
#define PIEZO_A0    35
#define PIEZO_A1    36
#define PIEZO_A2    37
#define PIEZO_A3    38

static const uint8_t piezoPins[] = {PIEZO_A0, PIEZO_A1, PIEZO_A2, PIEZO_A3};
#define NUM_PIEZOS  4

#define STATUS_LED  48

/* ===========================================================================
 *                          GLOBALS
 * =========================================================================*/

// Speed of sound (updated by Master calibration packets over UART)
static volatile float gSpeedOfSound = 343.0f;

// --- Piezo ISR state ---
static volatile int64_t  gPiezoTime       = 0;
static volatile uint8_t  gPiezoId         = 0xFF;
static volatile bool     gPiezoFired      = false;
static volatile int64_t  gLastPiezoTime   = 0;

// --- Acoustic (paddle-hit) trigger state ---
static volatile bool     gAcousticFired   = false;
static volatile int64_t  gAcousticTime    = 0;
static volatile int64_t  gLastAcousticTime = 0;

// --- Ring buffers (PSRAM) for 4 microphones ---
static int32_t*         gMicBuf[4]  = {nullptr};
static volatile uint32_t gMicWr[4]  = {0, 0, 0, 0};

// --- FreeRTOS handles ---
static TaskHandle_t      hTDOA       = nullptr;
static TaskHandle_t      hI2S0       = nullptr;
static TaskHandle_t      hI2S1       = nullptr;
static TaskHandle_t      hPiezoSend  = nullptr;
static QueueHandle_t     qPiezoEvt   = nullptr;     // PiezoEventPacket queue

// --- UART RX state (for incoming CalibrationPackets from Master) ---
static UartRxState       gUartRx;

/* ===========================================================================
 *                     PIEZO  INTERRUPT  SERVICE  ROUTINES
 * =========================================================================*/

static void IRAM_ATTR piezoISR(void* arg) {
    int64_t now = esp_timer_get_time();
    if (now - gLastPiezoTime < DEBOUNCE_US) return;
    gLastPiezoTime = now;

    uint8_t id = (uint8_t)(uintptr_t)arg;
    gPiezoTime  = now;
    gPiezoId    = id;
    gPiezoFired = true;

    // Queue a packet for fast forwarding to Master
    PiezoEventPacket pkt;
    pkt.type         = PKT_PIEZO_EVENT;
    pkt.nodeId       = NODE_ALPHA;
    pkt.sensorId     = id;
    pkt.zone         = ZONE_SIDE_A;
    pkt.timestamp_us = now;
    pkt.intensity    = 0;
    BaseType_t woken = pdFALSE;
    xQueueSendFromISR(qPiezoEvt, &pkt, &woken);

    // Also wake the TDOA task
    if (hTDOA) vTaskNotifyGiveFromISR(hTDOA, &woken);
    portYIELD_FROM_ISR(woken);
}

/* ===========================================================================
 *                     I2S  CONFIGURATION
 * =========================================================================*/

static void initI2SBus(i2s_port_t port, int sck, int ws, int sd) {
    i2s_config_t cfg = {};
    cfg.mode                 = (i2s_mode_t)(I2S_MODE_MASTER | I2S_MODE_RX);
    cfg.sample_rate          = I2S_SAMPLE_RATE;
    cfg.bits_per_sample      = I2S_BITS_PER_SAMPLE_32BIT;
    cfg.channel_format       = I2S_CHANNEL_FMT_RIGHT_LEFT;
    cfg.communication_format = I2S_COMM_FORMAT_STAND_I2S;
    cfg.intr_alloc_flags     = ESP_INTR_FLAG_LEVEL1;
    cfg.dma_buf_count        = 8;
    cfg.dma_buf_len          = 256;
    cfg.use_apll             = true;
    cfg.tx_desc_auto_clear   = false;
    cfg.fixed_mclk           = 0;
    i2s_driver_install(port, &cfg, 0, nullptr);

    i2s_pin_config_t pins = {};
    pins.bck_io_num   = sck;
    pins.ws_io_num    = ws;
    pins.data_out_num = I2S_PIN_NO_CHANGE;
    pins.data_in_num  = sd;
    i2s_set_pin(port, &pins);
}

/* ===========================================================================
 *              I2S  DMA  READ  TASKS  (pinned to Core 0)
 *  Each task reads stereo frames and de-interleaves into per-mic ring buffers.
 * =========================================================================*/

static void i2sReadTask0(void*) {
    int32_t dma[512];            // 256 stereo frames
    size_t  br;
    for (;;) {
        i2s_read(I2S_NUM_0, dma, sizeof(dma), &br, portMAX_DELAY);
        int frames = br / (2 * sizeof(int32_t));
        for (int i = 0; i < frames; ++i) {
            int32_t L = dma[i * 2];
            int32_t R = dma[i * 2 + 1];
            uint32_t idx0 = gMicWr[0] % RING_BUFFER_SAMPLES;
            uint32_t idx1 = gMicWr[1] % RING_BUFFER_SAMPLES;
            gMicBuf[0][idx0] = L;   gMicWr[0]++;
            gMicBuf[1][idx1] = R;   gMicWr[1]++;

            // --- acoustic paddle-hit detector (on Mic 0) ---
            int64_t now = esp_timer_get_time();
            if (abs(L) > ACOUSTIC_THRESHOLD &&
                (now - gLastPiezoTime > 50000) &&
                (now - gLastAcousticTime > 100000)) {
                gAcousticFired = true;
                gAcousticTime  = now;
                gLastAcousticTime = now;
                if (hTDOA) {
                    BaseType_t w = pdFALSE;
                    vTaskNotifyGiveFromISR(hTDOA, &w);
                }
            }
        }
    }
}
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

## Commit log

2026-03-31 Revise README with project details and updates
    Updated README.md to include additional details about the SPARK project, including features, architecture, wiring, and materials.
2026-05-25 Update JOURNAL.md with project progress and details
    Documented the project progress for S.P.A.R.K., including BOM, design changes, coding updates, and GitHub repository links.
2026-05-25 Update JOURNAL.md with project progress and details
    Added images, schematics, and detailed project updates including design changes and total time spent on various tasks.
2026-05-25 Revise JOURNAL.md with project updates and resources
    Updated JOURNAL.md with project details, images, and links. Adjusted descriptions and added new schematics and CAD files.
